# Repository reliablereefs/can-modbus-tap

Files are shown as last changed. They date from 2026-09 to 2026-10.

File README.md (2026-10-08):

# CAN / MODBUS tap

Listen-only probe for a 24 V accessory port that uses a USB-A shell. An ESP32-S3 records classic CAN frames, a collector stores them, and MODBUS RTU payloads inside those frames are decoded into request/response pairs and a register map.

The probe cannot transmit. The isolated CAN transceiver's TXD pin is tied to its logic supply, so the driver stays recessive, and the ESP32 TWAI controller runs in listen-only mode. Use it on equipment you are allowed to monitor.

## Bring-up before any connection

The USB-A plug is not USB. Do not plug it into a computer, and do not use a normal USB cable between the equipment port and anything else. A 24 V pin in that shell will damage a USB host.

1. With the tap unplugged, meter the equipment port.
2. Identify ground and the pin that sits near 24 V.
3. Scope the other two pins. Classic CAN idle holds both near 2.5 V. RS-485 idle is a differential offset without that 2.5 V pair bias.
4. Wire the tap's USB-A plug to match the measured port: pin 1 = 24 V, pin 2 = CANL, pin 3 = CANH, pin 4 = GND. See [docs/hardware.md](docs/hardware.md).
5. Power the tap from its USB-C port. The 24 V pin is measured and is not the tap's supply.
6. Confirm frames in the collector before trusting a bitrate lock.

If the scope does not show CAN bias, stop. This board's controller only decodes classic CAN. An RS-485 MODBUS RTU pair needs a different transceiver.

## Layout

```text
can-modbus-tap/
  docs/hardware.md     board, pinout, isolation, BOM notes
  docs/protocol.md     capture record, upload JSON, MODBUS pairing
  hardware/bom.csv
  firmware/            ESP-IDF project for ESP32-S3
  collector/           SQLite ingest, decode, and browser UI
```

```mermaid
flowchart LR
  port["Equipment port"] --> choke["Choke and TVS"]
  choke --> iso["ISO1042 TXD tied high"]
  iso --> esp["ESP32-S3 listen-only"]
  v24["24 V divider"] --> adc["ADS1115"]
  adc --> i2c["ISO1640"]
  i2c --> esp
  esp --> flash["Flash ring"]
  esp --> col["Collector"]
```

## Firmware

Requires ESP-IDF 5.3. The Wi-Fi SSID and collector URL are compile-time settings, so they stay out of the git tree.

```bash
cd firmware
idf.py set-target esp32s3
idf.py menuconfig   # CAN MODBUS Tap
idf.py build flash monitor
```

Set the SSID, password, and `TAP_COLLECTOR_URL`. Leave bitrate at 0 to scan 25 kbit/s through 1 Mbit/s. Set a fixed rate once the bus is identified. An empty SSID still records to the on-module flash ring.

The activity LED (GPIO2) stays on while frames arrive. GPIO5 is the TWAI transmit test point and is not routed to the transceiver.

## Collector

```bash
cd collector
go run ./cmd/collector -listen 0.0.0.0:8080 -db data/tap.db
```

Open `http://127.0.0.1:8080/`. Pages:

| Path | Contents |
| --- | --- |
| `/` | Raw CAN frames |
| `/modbus` | CRC-valid MODBUS RTU payloads |
| `/transactions` | Request paired with the next response, 500 ms window |
| `/map` | Register addresses sorted by how often they appear |
| `/v1/frames.csv` | Recent raw frames |

`POST /v1/frames` has no authentication. Run the collector on the lab network. Details are in [docs/protocol.md](docs/protocol.md).

```bash
cd collector && go test ./...
```

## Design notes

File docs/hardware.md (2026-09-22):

# Hardware

Passive classic-CAN tap. The field connector is a USB-A plug because the equipment port uses that shell. The plug carries 24 V, ground, and a differential pair. It is not a USB device and it must not be inserted into a USB host.

Power for the ESP32 comes from a separate USB-C receptacle. The 24 V pin is only measured, through an isolated ADC, so a wiring mistake on the field plug does not back-feed the computer used to program the tap.

## Zones

Keep logic ground and bus ground apart with a milled slot under the ISO1042 and the ISO1640. The slot is 2 mm wide, which fits between those packages' pads, and it runs 8 mm past the pads so the creepage path has to go around the slot. The RFM-0505S pins are 2.54 mm apart, so the slot stops before that module; its isolation is the module's own barrier. Logic ground and bus ground meet nowhere.

| Zone | Ground | Supply |
| --- | --- | --- |
| Logic | `GND_LOG` | USB-C 5 V, then 3.3 V for the ESP32 |
| Bus | `GND_BUS` | Isolated 5 V for the CAN transceiver, isolated 3.3 V for the ADC |

## USB-A plug

Standard USB-A pin numbers, used here for a different electrical assignment. Confirm against the equipment port with a meter before connecting. Swap CANH/CANL or the 24 V pin only after that measurement. Do not guess.

| Pin | USB name | This tap |
| --- | --- | --- |
| 1 | VBUS | +24 V sense |
| 2 | D− | CANL |
| 3 | D+ | CANH |
| 4 | GND | Bus ground |
| Shell | Shield | Bus ground |

There is no USB-A receptacle on the tap, so a PC cable cannot be plugged into the 24 V pins through this board.

## CAN front end

Population is ISO1042 in the 16-pin SOIC (DW). Pin numbers below are that package.

| Pin | Name | Connect to |
| --- | --- | --- |
| 1 | VCC1 | `3V3_LOG` |
| 2, 8 | GND1 | `GND_LOG` |
| 3 | TXD | `3V3_LOG` directly |
| 5 | RXD | ESP32 GPIO4 |
| 9, 10, 15 | GND2 | `GND_BUS` |
| 11 and 16 | VCC2 | `5V_BUS`, tied together |
| 12 | CANL | choke, then USB-A pin 2 |
| 13 | CANH | choke, then USB-A pin 3 |

TXD high is recessive. Tying pin 3 to VCC1 means the transceiver cannot drive a dominant bit. The ESP32 still needs a TWAI TX GPIO for the driver; that is GPIO5, a test point, and it does not reach the transceiver. Listen-only mode is a second interlock: the controller does not send data, acknowledgements, or error frames.

100 nF from each VCC pin to its own ground. Common-mode choke in series with CANH and CANL, then NUP2105 from both lines to bus ground. Footprint a 120 Ω resistor across the pair and leave it unstuffed. A tap in the middle of a bus must not add termination. Stuff it only if this node is intentionally an end of the bus, and then only one end.

The ISO1042 tolerates CAN FD on the wire. The ESP32-S3 TWAI controller does not decode CAN FD. A FD-only bus will fail bitrate lock.

## 24 V sense

Bus side only, so the divider never crosses the slot.

`24V` — 91.0 kΩ 1% — node — 12.0 kΩ 1% — `GND_BUS`. 100 nF across the 12.0 kΩ. 1 kΩ from the node to ADS1115 AIN0. BZT52C3V6 from AIN0 to `GND_BUS`.

ADS1115 ADDR pin to `GND_BUS` (I2C address 0x48). AIN1–AIN3 open. Power the ADC and ISO1640 side 2 from `3V3_BUS`, which is an AP2112 from `5V_BUS`.

At 24.00 V the ADC sees 24 × 12 / 103 = 2.796 V. Firmware programs PGA ±4.096 V and reports `bus_mv = code × 103 / 96`.

I2C crosses the slot on ISO1640. 4.7 kΩ pull-ups on each side to that side's 3.3 V. ESP32 GPIO6 is SDA, GPIO7 is SCL.

## Logic power and USB-C

USB-C VBUS feeds AP7361C-33 (1 A) for the ESP32 module. 10 µF on 3.3 V. CC1 and CC2 each have 5.1 kΩ to `GND_LOG`. D+ is GPIO20, D− is GPIO19, each through 22 Ω.

EN has 10 kΩ to 3.3 V, 1 µF to ground, and a button to ground. GPIO0 has 10 kΩ to 3.3 V and a BOOT button to ground. GPIO2 drives the activity LED through 330 Ω.

`5V_USB` also feeds the RECOM RFM-0505S, a 1 W SIP4 module. RECOM rates it 1 kVDC. Pin 1 is -Vin, pin 2 is +Vin, pin 3 is -Vout, and pin 4 is +Vout. The module output is `5V_BUS`.

## ESP32-S3-WROOM-1-N8

| GPIO | Function |
| --- | --- |
| 2 | Activity LED |
| 4 | TWAI RX from ISO1042 RXD |
| 5 | TWAI TX test point only |
| 6 | I2C SDA |
| 7 | I2C SCL |
| 19 | USB D− |
| 20 | USB D+ |
| 0 | BOOT strap, button to ground |

Do not route GPIO26–32; the module uses them for flash.

## How to tell CAN from RS-485

Measure the undriven differential pair against bus ground.

- Both lines near 2.5 V, and they kick apart by about 2 V during a frame: classic CAN. This board matches that.
- One line sits a few hundred millivolts above the other and the common mode is not 2.5 V: likely RS-485 MODBUS RTU. Do not keep this transceiver on that pair. A later board would swap the ISO1042 for an ISO1410 with the driver-enable pin tied off, and the ESP32 would listen on a UART.

## Parts

See [hardware/bom.csv](../hardware/bom.csv). The schematic is [hardware/kicad/can-modbus-tap.kicad_sch](../hardware/kicad/can-modbus-tap.kicad_sch).

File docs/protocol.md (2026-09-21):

# Capture and MODBUS decode

The tap stores every classic CAN frame it locks onto. MODBUS decoding is a best-effort pass over those bytes. The raw frame is kept either way.

## On-device record

Each flash record is 32 bytes, little-endian:

| Offset | Field |
| --- | --- |
| 0 | Magic `0xC0FFEE42` |
| 4 | Sequence, starting at 1 |
| 8 | `ts_us`, monotonic microseconds from boot |
| 16 | CAN id |
| 20 | DLC |
| 21 | Flags: bit 0 extended id, bit 1 remote frame |
| 22 | Index into the bitrate table |
| 24 | 8 data bytes |

The ring lives in the `caps` partition (about 6 MB, 32-byte records). The upload cursor is in NVS. A retried upload of the same sequence is ignored by the collector.

Bitrates the scanner tries, in order: 250k, 500k, 125k, 100k, 50k, 1M, 800k, 25k. A rate is locked when it collects at least two frames in 400 ms without a high receive-error count. Set `TAP_BITRATE` once the rate is known so an idle bus does not have to be scanned.

## Upload

`POST /v1/frames` with `Content-Type: application/json`.

```json
{
  "device_id": "aabbccddeeff",
  "bus_mv": 24120,
  "dropped": 0,
  "bitrate": 250000,
  "boot_unix_us": 1700000000000000,
  "frames": [
    {
      "seq": 12,
      "ts_us": 1530000,
      "id": 385,
      "ext": false,
      "rtr": false,
      "dlc": 8,
      "bitrate": 250000,
      "data": "010300000001"
    }
  ]
}
```

`device_id` is the Wi-Fi MAC, or the menuconfig override. `dropped` is the count of frames that missed the RAM queue since boot. `boot_unix_us` is zero until SNTP locks; after that the collector sets event time to `boot_unix_us + ts_us`, which is comparable across taps. `bus_mv` is -1 when the ADS1115 does not answer.

Empty `frames` is a heartbeat so bus voltage is recorded while the bus is idle. The collector answers `{"stored": N}` where N is newly inserted data frames.

## MODBUS

Bytes are appended per device and CAN id. A gap over 10 ms clears a partial frame. A candidate is accepted when the MODBUS CRC-16 matches and the length matches a known function:

| Function | Request | Response |
| --- | --- | --- |
| 1, 2, 3, 4 | 8 bytes, quantity in range | 5 + byte count |
| 5, 6 | 8 bytes, identical to the response | same 8 bytes, paired when the echo repeats within 500 ms |
| 15, 16 | 9 + byte count | 8 bytes |

Slave address 0 and addresses above 247 are ignored. Exception responses (function code with the high bit set) are 5 bytes. Read Holding (function 3) and Read Input (function 4) responses must have an even byte count.

A CAN id that carries a whole RTU frame in one or more consecutive frames decodes on its own. Pairing does not require the response to use the same CAN id. It matches slave address and function code inside 500 ms, and copies the register address from the request.

If nothing decodes, the payload is not this RTU layout. The frames page is still the source of truth. Some devices put the node address in the CAN id and omit the RTU slave byte; that will not decode until a second pass is written, and the raw bytes are what that pass would use.

## Working a register map

1. Lock bitrate and confirm raw frames.
2. Open `/modbus` and check that function codes and slave addresses look stable rather than random.
3. Open `/transactions` and check latency. Milliseconds, not tens of milliseconds, usually means the response belongs to that request.
4. Open `/map`. Repeated `(slave, function, address, quantity)` rows are the command set. A function 3 row is a read of holding registers. A function 16 row is a write. The address column is the register the master asked for.
5. Export `/v1/frames.csv` when you want to try a different grouping offline. Do not delete the raw frames; the decoder can be wrong about an ambiguous 8-byte function 5 or 6 frame, and the hex is the check.

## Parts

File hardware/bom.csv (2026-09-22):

Qty | Ref | Value | Package | Manufacturer | Part | Notes
1 | U1 | ESP32-S3-WROOM-1-N8 | Module | Espressif | ESP32-S3-WROOM-1-N8 | 8 MB quad flash. Classic CAN only.
1 | U2 | ISO1042 | SOIC-16 | Texas Instruments | ISO1042BDW | Isolated CAN. TXD hard-tied to VCC1. Tie VCC2 pins 11 and 16.
1 | U3 | I2C isolator | SOIC-8 | Texas Instruments | ISO1640BD | Bus-side ADS1115 to ESP32. 3.3 V both sides.
1 | U4 | ADC 16-bit | VSSOP-10 | Texas Instruments | ADS1115IDGSR | ADDR to bus GND. AIN0 is the 24 V divider.
1 | U5 | 5V to 5V 1W isolated | SIP4 | RECOM | RFM-0505S | Pin 1 -Vin, 2 +Vin, 3 -Vout, 4 +Vout. RECOM rates it 1 kVDC.
1 | U6 | 3.3V 1A LDO | SOT-223 | Diodes Inc | AP7361C-33E-13 | USB VBUS to ESP32 3.3 V.
1 | U7 | 3.3V 600mA LDO | SOT-23-5 | Diodes Inc | AP2112K-3.3TRG1 | Bus-side 5 V to 3.3 V for ADS1115 and ISO1640 side 2.
1 | J1 | USB-A plug | USB3-A horizontal | Würth | 692112030100 | Field connector. Not a USB port. See docs/hardware.md pinout.
1 | J2 | USB-C receptacle | USB-C 16P top-mount | GCT | USB4105 | Logic power and native USB programming.
1 | L1 | CAN common-mode choke | ACT45B | TDK | ACT45B-510-2P-TL003 | Between J1 and U2.
1 | D1 | CAN TVS | SOT-23 | onsemi | NUP2105LT1G | CANH CANL and bus GND.
1 | D2 | 3.6V zener | SOD-123 | Nexperia | BZT52C3V6 | Clamp ADS1115 AIN0 to bus GND.
1 | D3 | LED | 0603 |  |  | Activity. On while frames are arriving.
2 | SW1 SW2 | Tactile | 6mm |  |  | SW1 BOOT to GPIO0. SW2 reset to EN.
1 | R1 | 91.0k 1% | 0603 |  |  | 24 V divider top. Bus side only.
1 | R2 | 12.0k 1% | 0603 |  |  | 24 V divider bottom.
1 | R3 | 1k | 0603 |  |  | Series into ADS1115 AIN0.
2 | R4 R5 | 4.7k | 0603 |  |  | I2C pull-ups on the logic side to 3V3_LOG.
2 | R6 R7 | 4.7k | 0603 |  |  | I2C pull-ups on the bus side to 3V3_BUS.
2 | R8 R9 | 5.1k | 0603 |  |  | USB-C CC1 and CC2 to logic GND.
2 | R10 R11 | 10k | 0603 |  |  | EN and GPIO0 pull-ups to 3V3_LOG.
1 | R12 | 330 | 0603 |  |  | LED series.
1 | R13 | 120 1% | 0603 |  |  | DNP. Termination footprint. Leave open.
2 | R14 R15 | 22 | 0603 |  |  | USB D+ and D- series. Optional but recommended.
1 | C1 | 10uF 10V | 0805 |  |  | 3V3_LOG bulk.
4 | C2 C3 C4 C5 | 100nF | 0402 |  |  | U2 VCC1 U2 VCC2 U6 U7.
2 | C6 C7 | 10uF 10V | 0805 |  |  | 5V_BUS and 3V3_BUS bulk.
1 | C8 | 100nF | 0402 |  |  | Across R2.
1 | C9 | 1uF | 0402 |  |  | EN to logic GND.
1 | JP1 | Termination jumper | 0.1in header |  |  | Open. Stuff only if this node is a physical bus end.
1 | TP1 | TWAI TX test point | Pad |  |  | GPIO5. Not connected to the transceiver.

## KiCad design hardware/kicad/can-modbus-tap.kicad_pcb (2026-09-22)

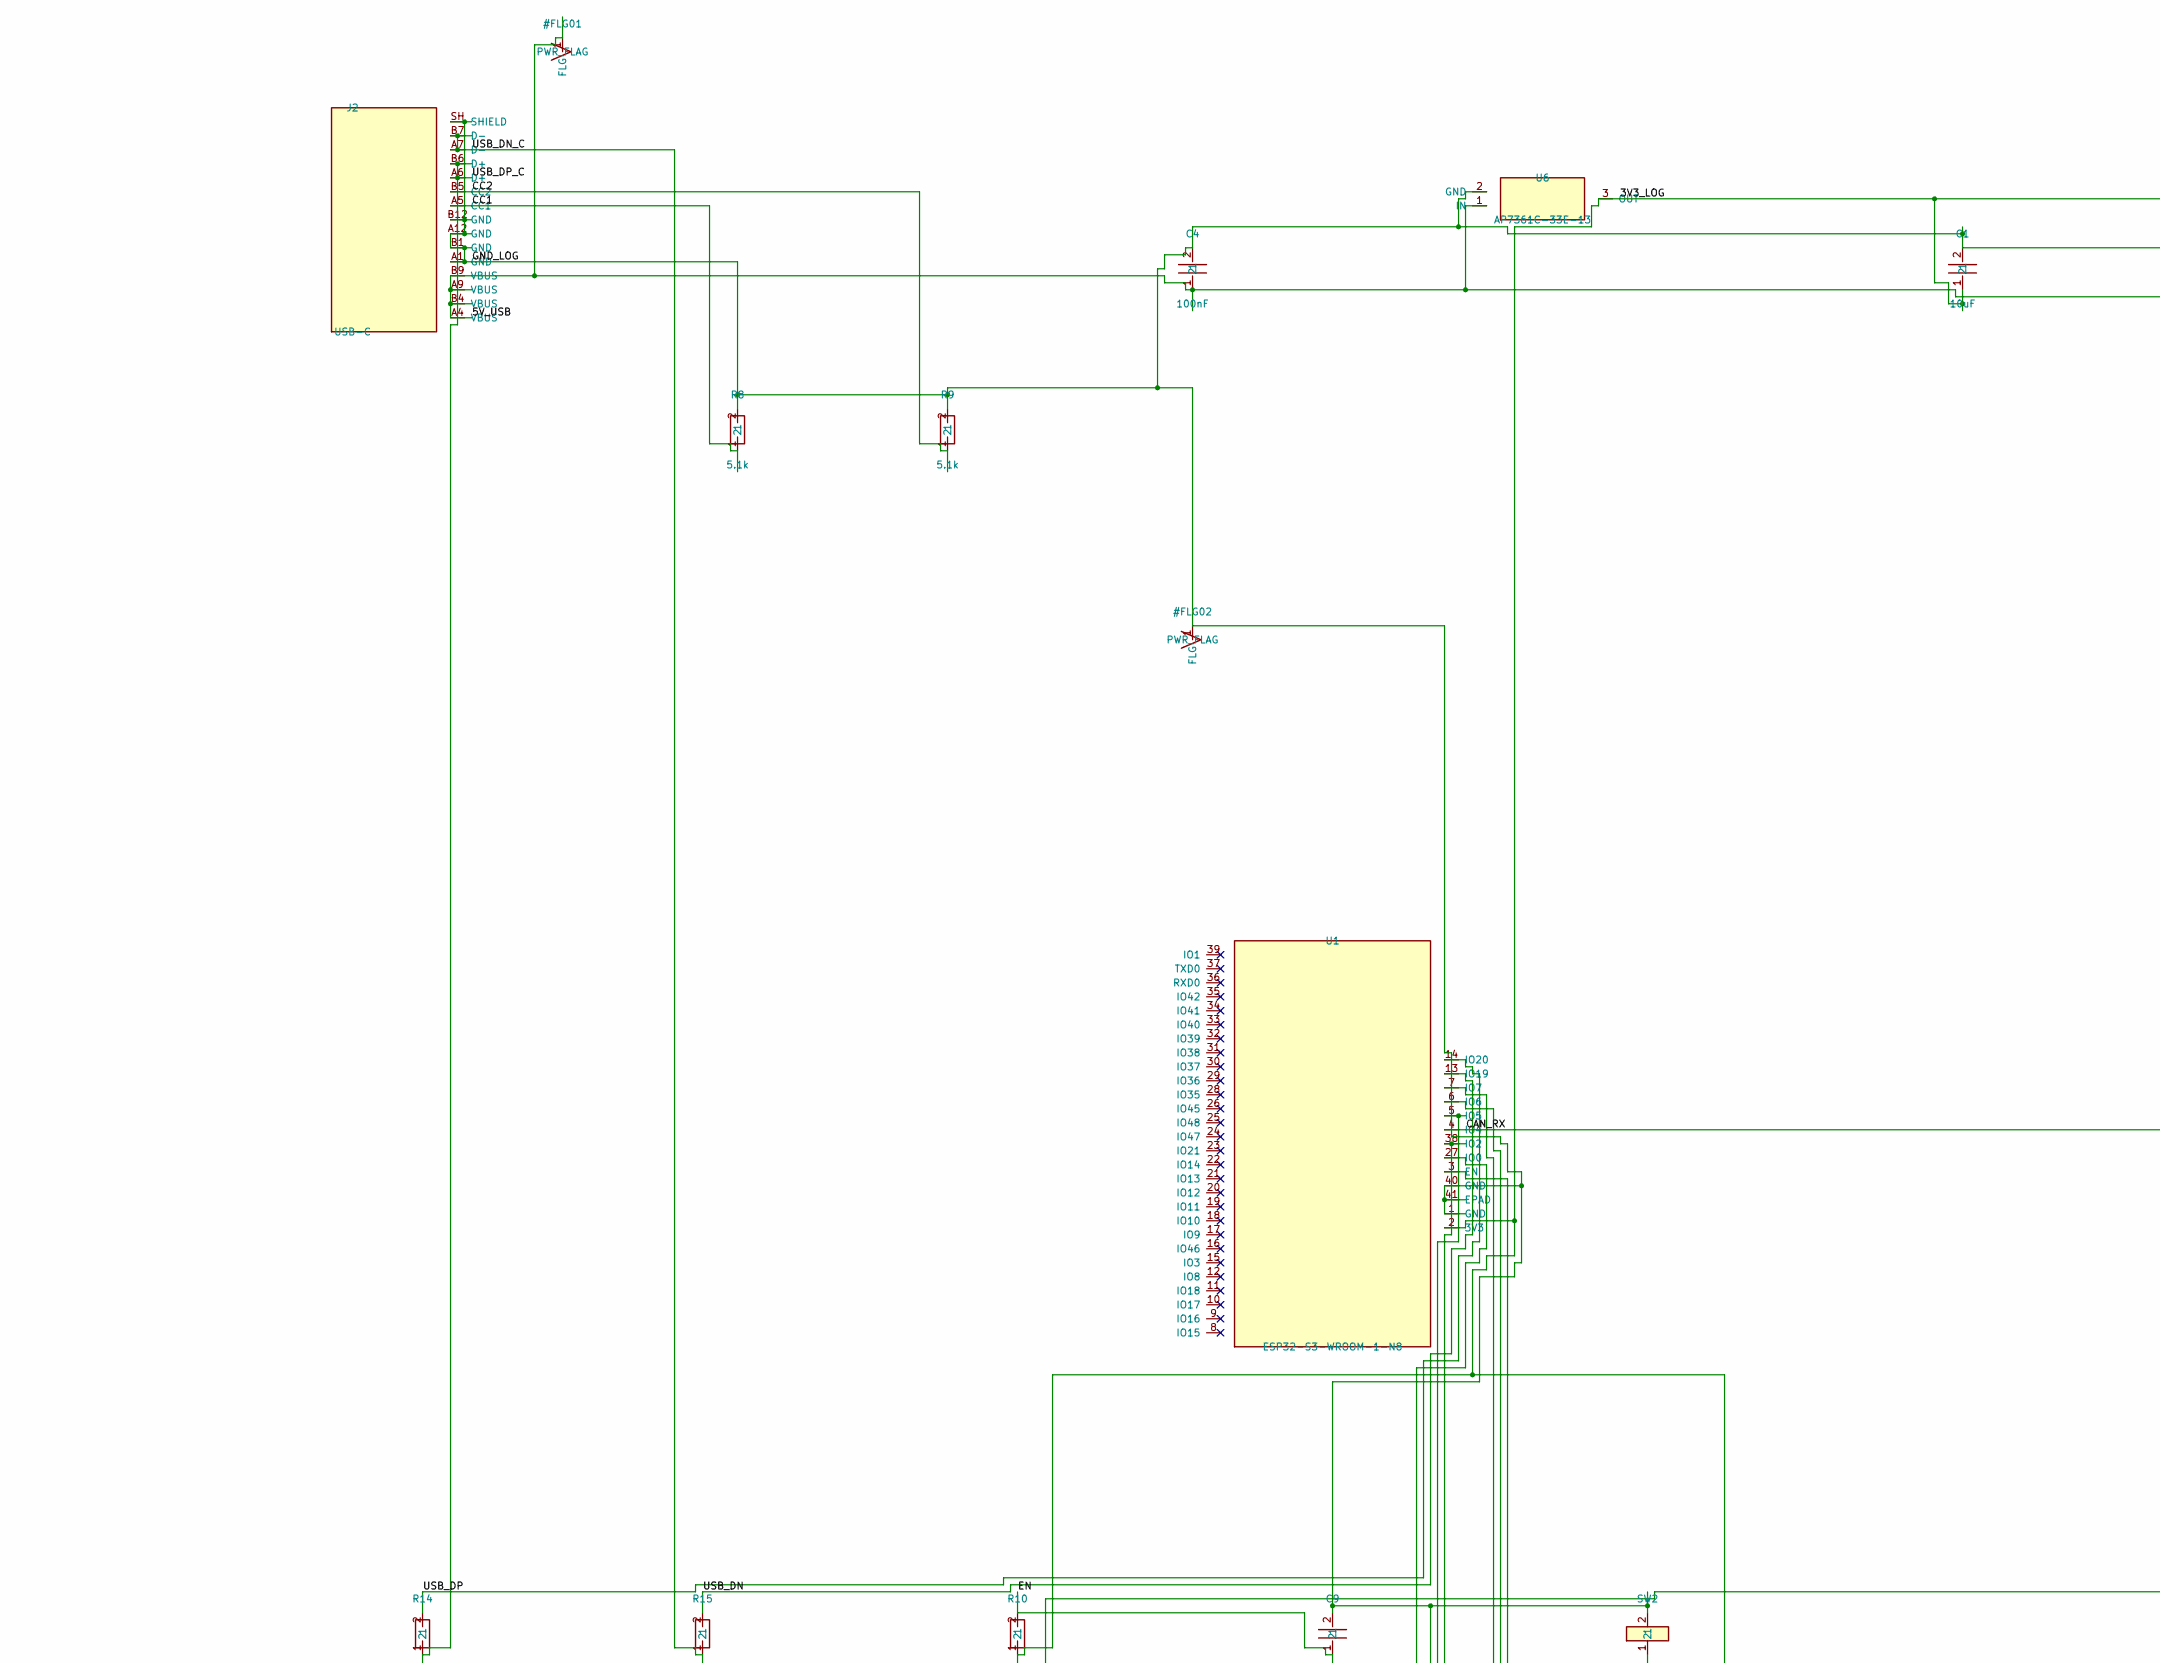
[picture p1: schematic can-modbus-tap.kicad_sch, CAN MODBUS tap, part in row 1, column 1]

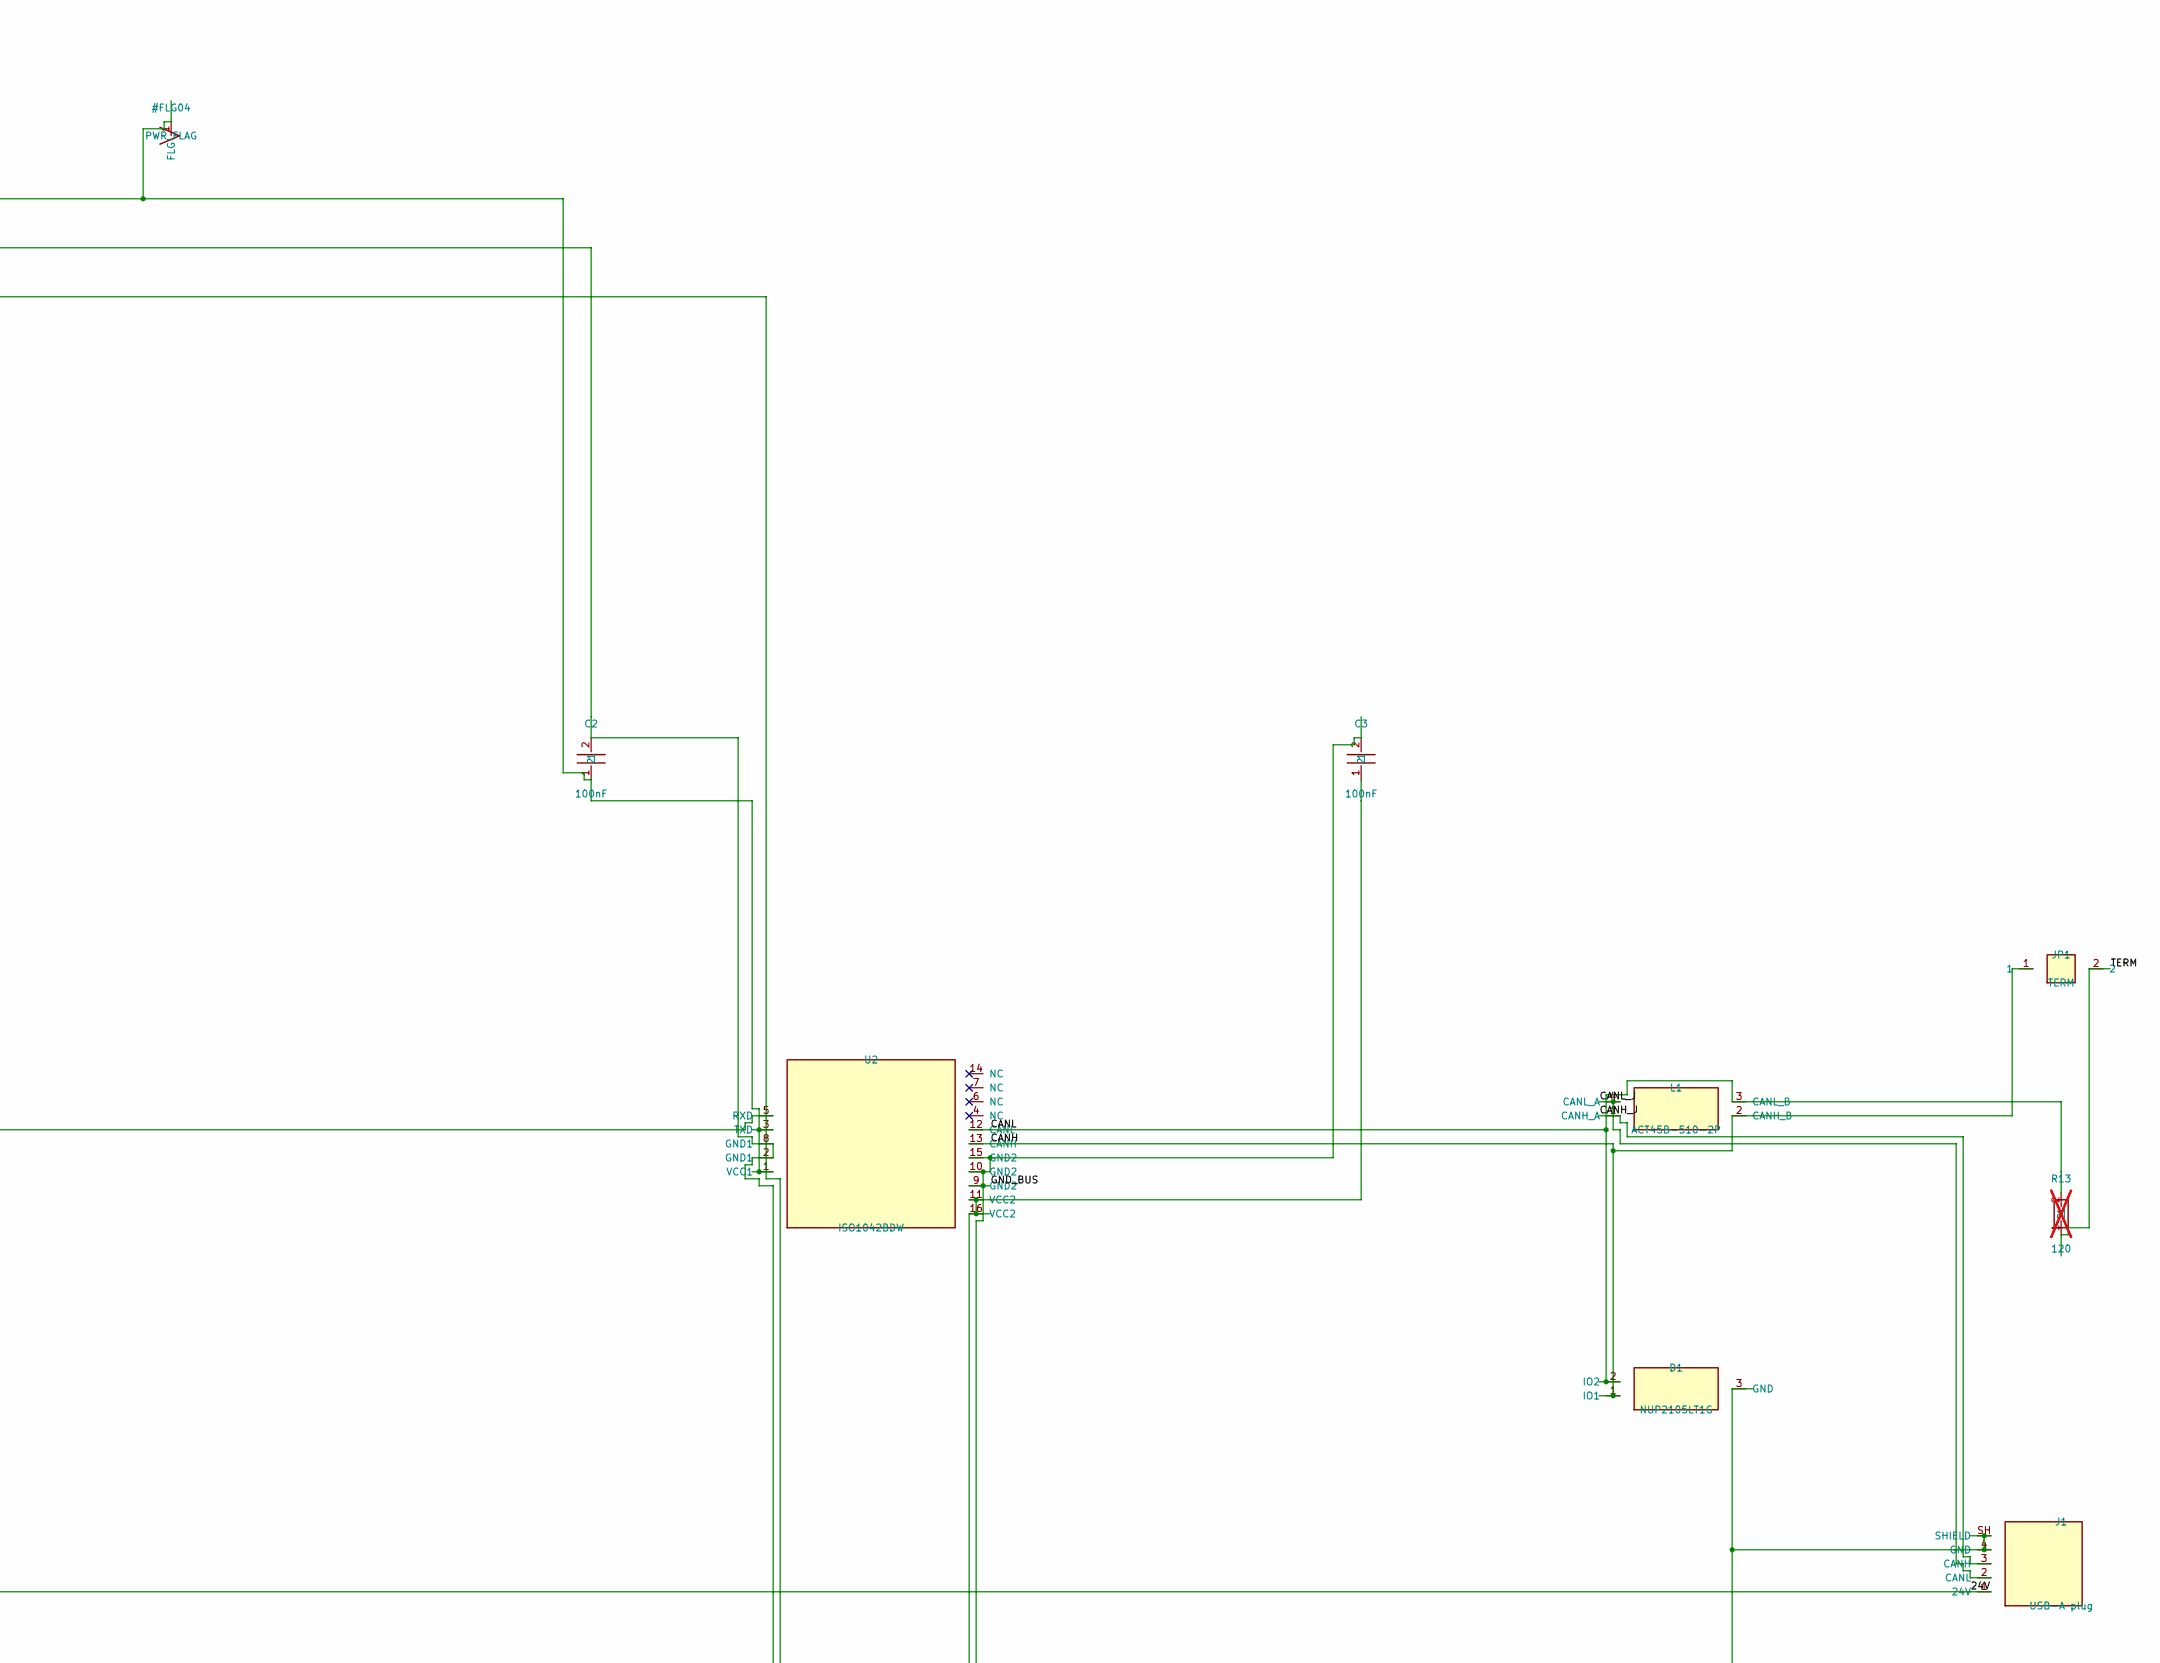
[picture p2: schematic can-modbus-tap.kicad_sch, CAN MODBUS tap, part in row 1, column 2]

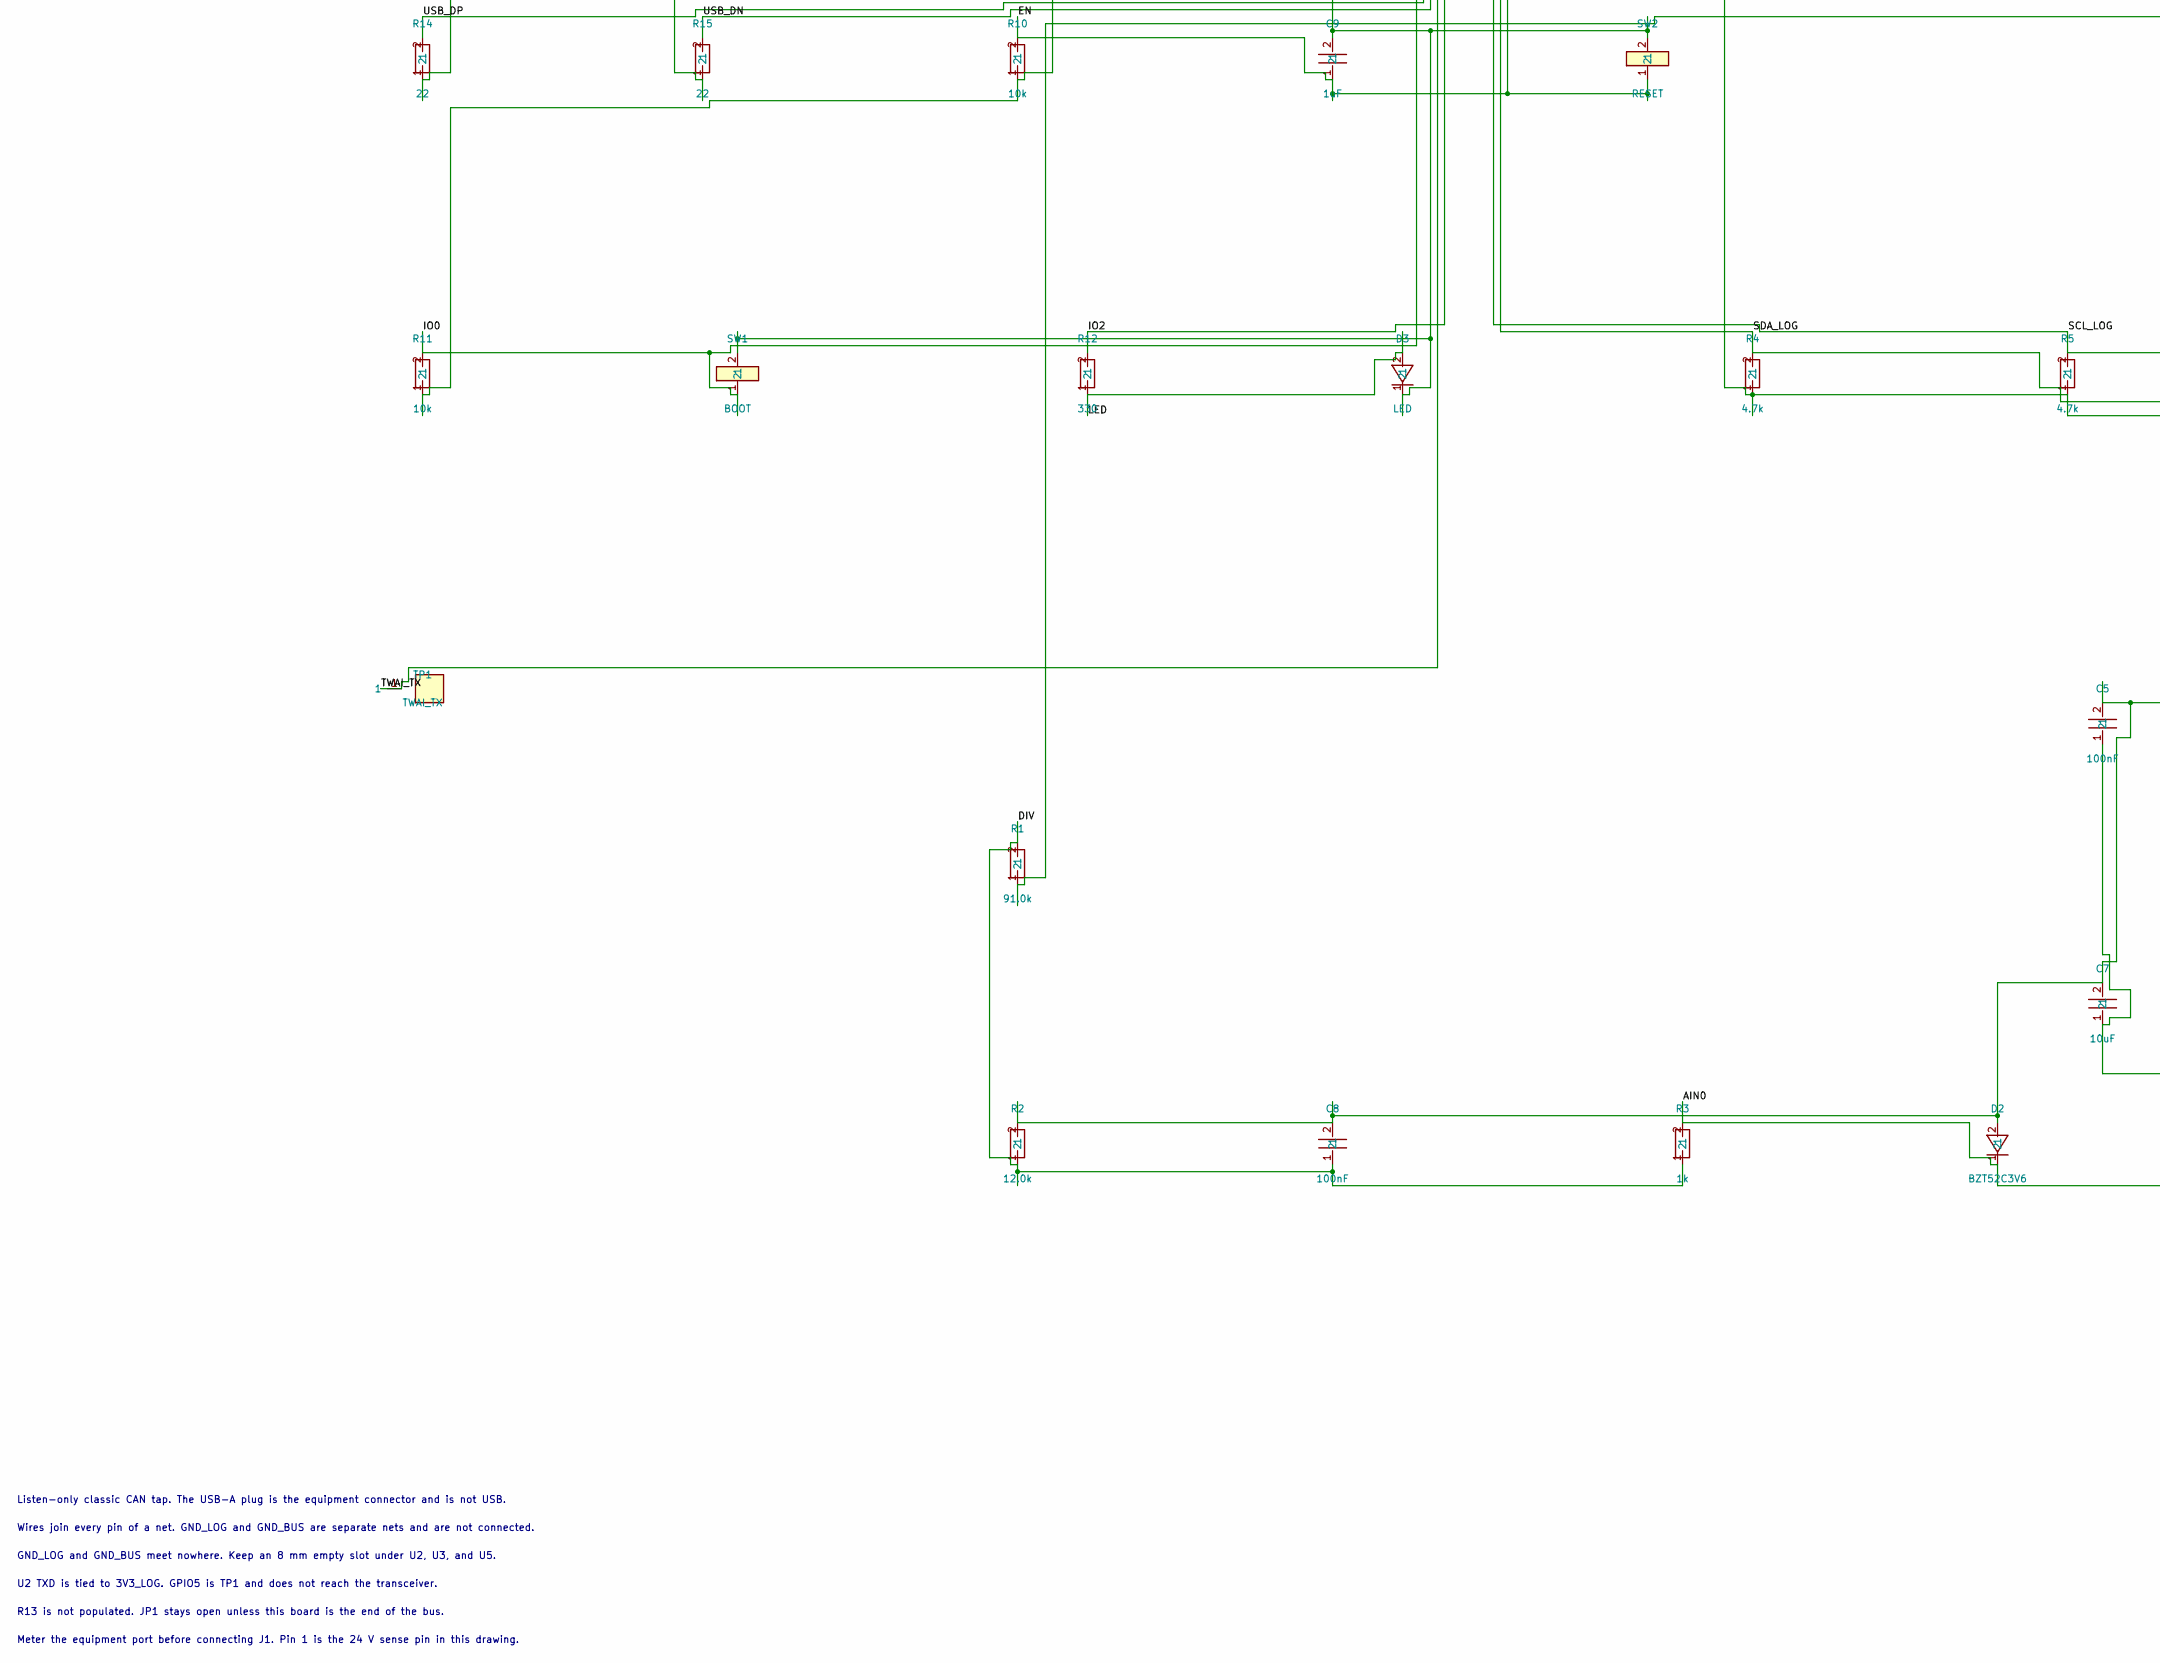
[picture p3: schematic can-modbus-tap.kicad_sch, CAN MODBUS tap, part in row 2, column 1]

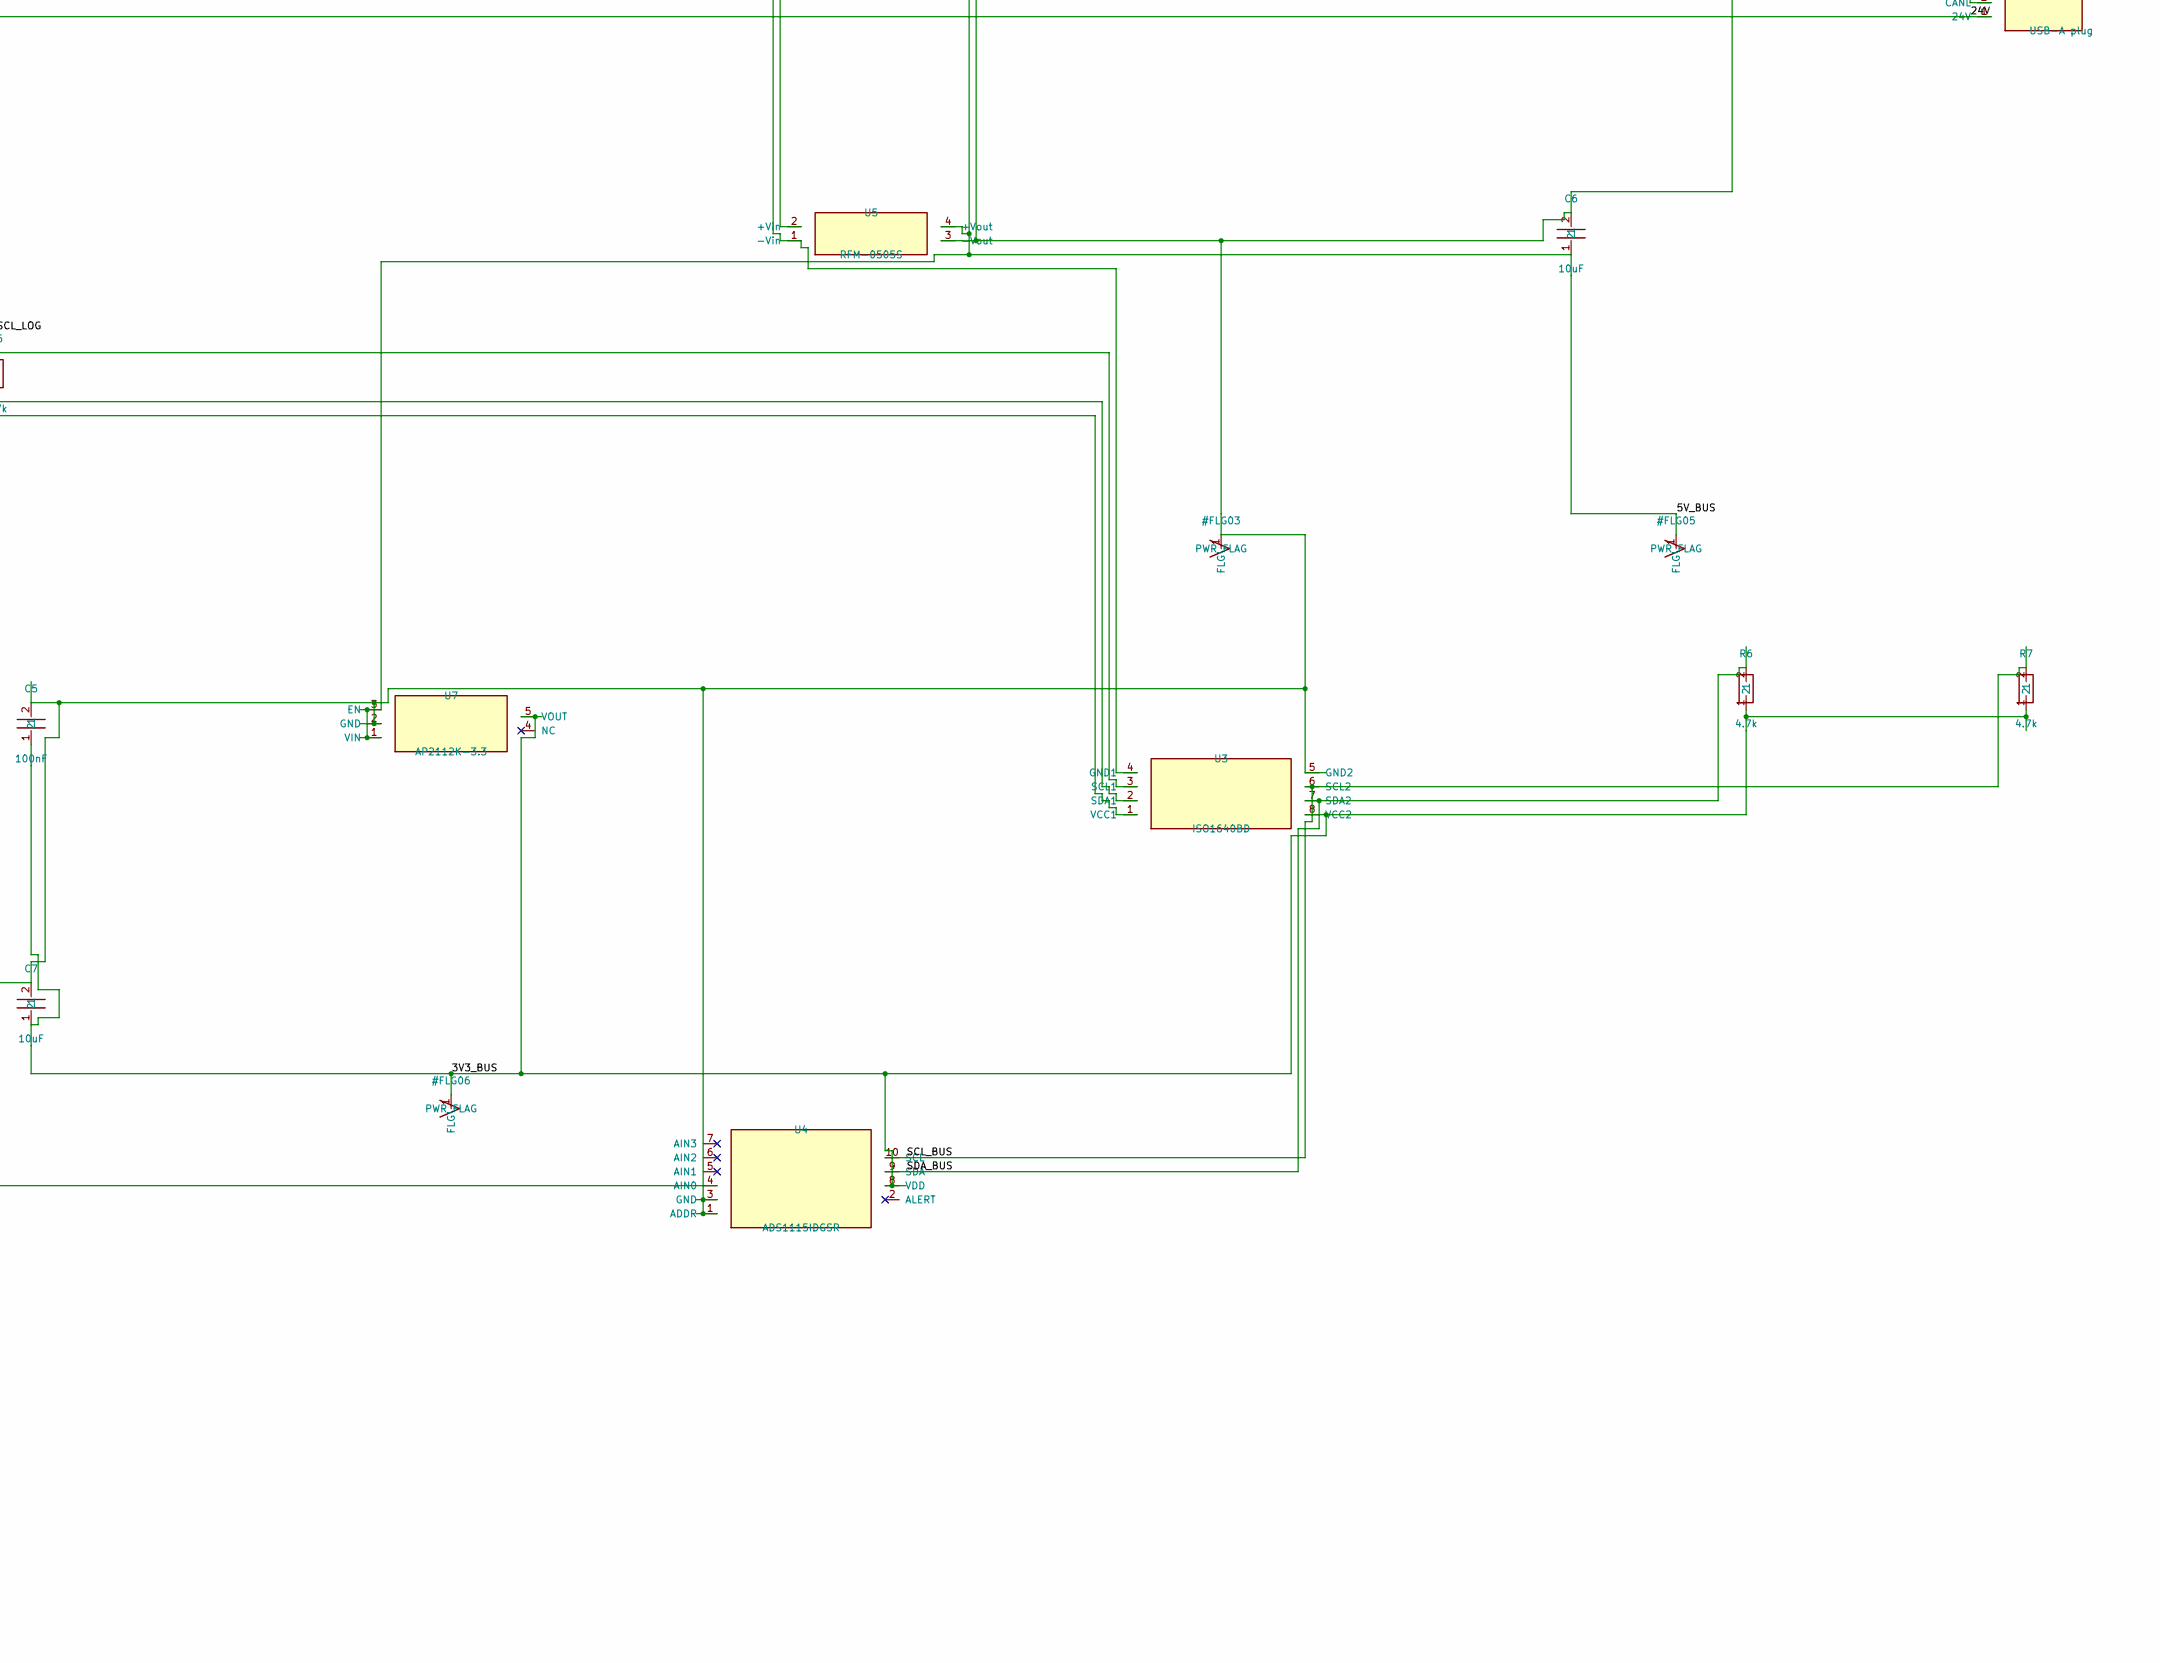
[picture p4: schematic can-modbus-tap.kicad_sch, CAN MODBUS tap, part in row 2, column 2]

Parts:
C1, C6, C7: 10uF; C_0805_2012Metric
C2, C3, C4, C5, C8: 100nF; C_0402_1005Metric
C9: 1uF; C_0402_1005Metric
D1: NUP2105LT1G; SOT-23
D2: BZT52C3V6; D_SOD-123
D3: LED; LED_0603_1608Metric
J1: USB-A plug; USB3_A_Plug_Wuerth_692112030100_Horizontal
J2: USB-C; USB_C_Receptacle_GCT_USB4105-xx-A_16P_TopMnt_Horizontal
JP1: TERM; PinHeader_1x02_P2.54mm_Vertical
L1: ACT45B-510-2P
R1: 91.0k; R_0603_1608Metric
R2: 12.0k; R_0603_1608Metric
R3: 1k; R_0603_1608Metric
R4, R5, R6, R7: 4.7k; R_0603_1608Metric
R8, R9: 5.1k; R_0603_1608Metric
R10, R11: 10k; R_0603_1608Metric
R12: 330; R_0603_1608Metric
R13: 120; R_0603_1608Metric; not fitted
R14, R15: 22; R_0603_1608Metric
SW1: BOOT; SW_PUSH_6mm
SW2: RESET; SW_PUSH_6mm
TP1: TWAI_TX; TestPoint_Pad_D1.5mm
U1: ESP32-S3-WROOM-1-N8; ESP32-S3-WROOM-1
U2: ISO1042BDW; SOIC-16W_7.5x10.3mm_P1.27mm
U3: ISO1640BD; SOIC-8_3.9x4.9mm_P1.27mm
U4: ADS1115IDGSR; MSOP-10_3x3mm_P0.5mm
U5: RFM-0505S; RECOM_RFM-0505S
U6: AP7361C-33E-13; SOT-223-3_TabPin2
U7: AP2112K-3.3; SOT-23-5

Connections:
3V3_BUS: C5.1, C7.1, R6.1, R7.1, U3.8 (VCC2), U4.8 (VDD), U7.5 (VOUT)
3V3_LOG: C1.1, C2.1, R4.1, R5.1, R10.1, R11.1, U1.2 (3V3), U2.1 (VCC1), U2.3 (TXD), U3.1 (VCC1), U6.3 (OUT)
5V_BUS: C3.1, C6.1, U2.11 (VCC2), U2.16 (VCC2), U5.4 (+Vout), U7.1 (VIN), U7.3 (EN)
5V_USB: C4.1, J2.A4 (VBUS), J2.A9 (VBUS), J2.B4 (VBUS), J2.B9 (VBUS), U5.2 (+Vin), U6.1 (IN)
24V: J1.1 (24V), R1.1
AIN0: D2.1, R3.2, U4.4 (AIN0)
CANH: D1.1 (IO1), JP1.1, L1.2 (CANH_B), U2.13 (CANH)
CANH_J: J1.3 (CANH), L1.1 (CANH_A)
CANL: D1.2 (IO2), L1.3 (CANL_B), R13.2, U2.12 (CANL)
CANL_J: J1.2 (CANL), L1.4 (CANL_A)
CAN_RX: U1.4 (IO4), U2.5 (RXD)
CC1: J2.A5 (CC1), R8.1
CC2: J2.B5 (CC2), R9.1
DIV: C8.1, R1.2, R2.1, R3.1
EN: C9.1, R10.2, SW2.1, U1.3 (EN)
GND_BUS: C3.2, C5.2, C6.2, C7.2, C8.2, D1.3 (GND), D2.2, J1.4 (GND), J1.SH (SHIELD), R2.2, U2.9 (GND2), U2.10 (GND2), U2.15 (GND2), U3.5 (GND2), U4.1 (ADDR), U4.3 (GND), U5.3 (-Vout), U7.2 (GND)
GND_LOG: C1.2, C2.2, C4.2, C9.2, D3.1, J2.A1 (GND), J2.A12 (GND), J2.B1 (GND), J2.B12 (GND), J2.SH (SHIELD), R8.2, R9.2, SW1.2, SW2.2, U1.1 (GND), U1.40 (GND), U1.41 (EPAD), U2.2 (GND1), U2.8 (GND1), U3.4 (GND1), U5.1 (-Vin), U6.2 (GND)
IO0: R11.2, SW1.1, U1.27 (IO0)
IO2: R12.2, U1.38 (IO2)
LED: D3.2, R12.1
SCL_BUS: R7.2, U3.6 (SCL2), U4.10 (SCL)
SCL_LOG: R5.2, U1.7 (IO7), U3.3 (SCL1)
SDA_BUS: R6.2, U3.7 (SDA2), U4.9 (SDA)
SDA_LOG: R4.2, U1.6 (IO6), U3.2 (SDA1)
TERM: JP1.2, R13.1
TWAI_TX: TP1.1, U1.5 (IO5)
USB_DN: R15.2, U1.13 (IO19)
USB_DN_C: J2.A7 (D-), J2.B7 (D-), R15.1
USB_DP: R14.2, U1.14 (IO20)
USB_DP_C: J2.A6 (D+), J2.B6 (D+), R14.1

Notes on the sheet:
Listen-only classic CAN tap. The USB-A plug is the equipment connector and is not USB.
Wires join every pin of a net. GND_LOG and GND_BUS are separate nets and are not connected.
GND_LOG and GND_BUS meet nowhere. Keep an 8 mm empty slot under U2, U3, and U5.
U2 TXD is tied to 3V3_LOG. GPIO5 is TP1 and does not reach the transceiver.
R13 is not populated. JP1 stays open unless this board is the end of the bus.
Meter the equipment port before connecting J1. Pin 1 is the 24 V sense pin in this drawing.

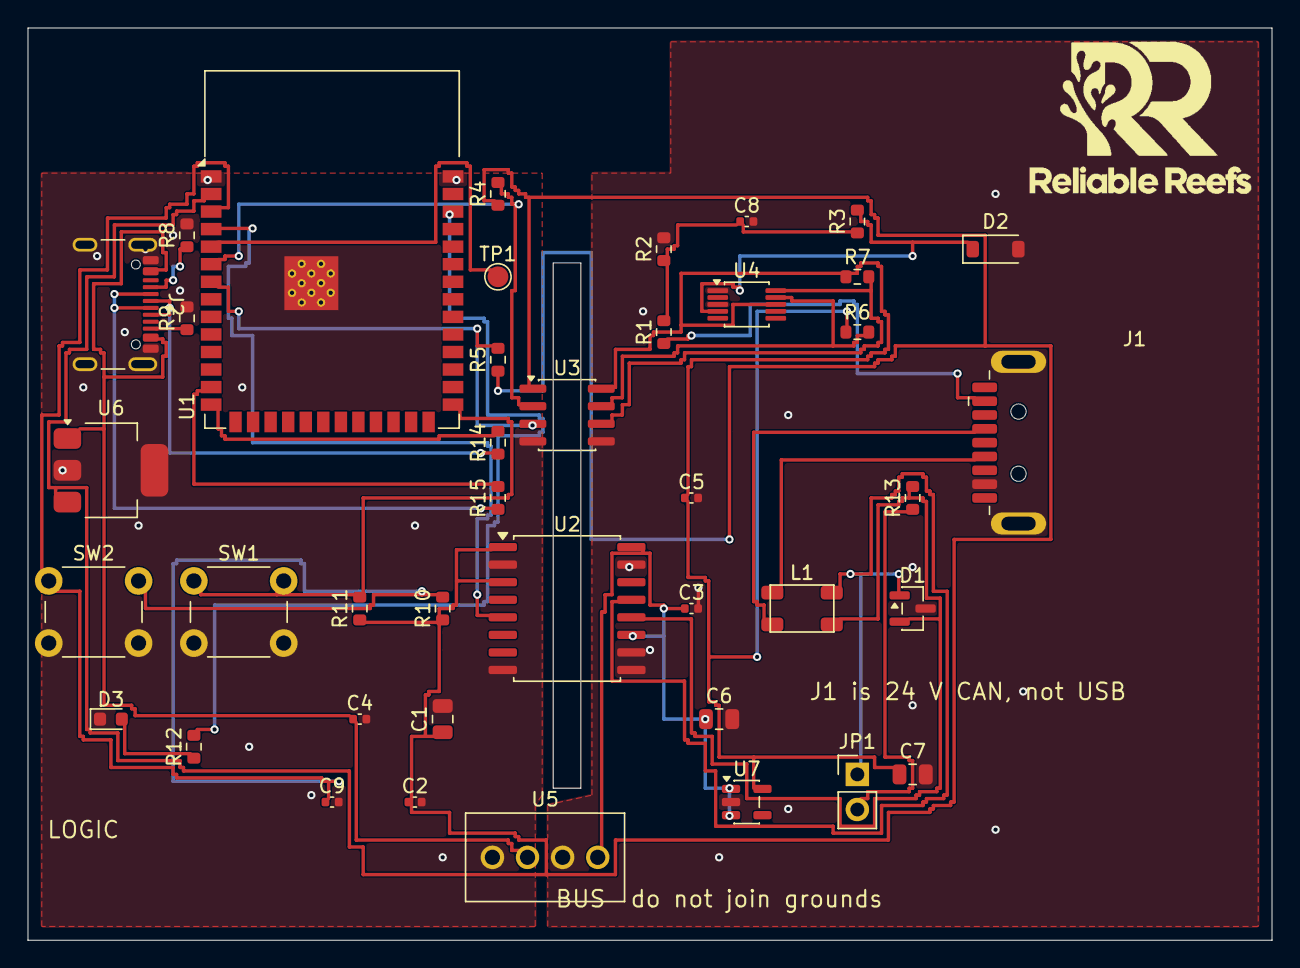
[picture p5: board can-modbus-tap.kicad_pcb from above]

Board: 2 copper layers, 90.0 x 66.0 mm, 41 parts (0 on the bottom side), 30 nets.

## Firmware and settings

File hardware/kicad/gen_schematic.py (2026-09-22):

#!/usr/bin/env python3
"""Generate the CAN / MODBUS tap schematic.

KiCad is not required to regenerate the file. Open hardware/kicad/can-modbus-tap.kicad_sch
in KiCad 8 or 9. Symbols are embedded, so no symbol library is required.
"""

from __future__ import annotations

import heapq
import uuid
from collections import defaultdict
from dataclasses import dataclass, field
from pathlib import Path

GRID = 1.27
OUT = Path(__file__).with_name("can-modbus-tap.kicad_sch")
PROJECT = "can-modbus-tap"


def mm(units: float) -> str:
    value = round(units * GRID, 4)
    text = f"{value:.4f}".rstrip("0").rstrip(".")
    return text if text else "0"


def q(text: str) -> str:
    return '"' + text.replace("\\", "\\\\").replace('"', '\\"') + '"'


def uid() -> str:
    return str(uuid.uuid4())


@dataclass
class Pin:
    num: str
    name: str
    side: str  # L R U D
    etype: str
    x: float = 0
    y: float = 0
    angle: int = 0


@dataclass
class Sym:
    lib_id: str
    pins: list[Pin]
    body_w: float = 10
    graphics: str = "box"

    def layout(self) -> None:
        groups = {side: [pin for pin in self.pins if pin.side == side] for side in "LRUD"}
        for side in "LR":
            pins = groups[side]
            span = (len(pins) - 1) * 2 if pins else 0
            y = -span / 2
            for pin in pins:
                pin.y = y
                pin.x = -self.body_w if side == "L" else self.body_w
                pin.angle = 180 if side == "L" else 0
                y += 2
        for side in "UD":
            pins = groups[side]
            span = (len(pins) - 1) * 2 if pins else 0
            x = -span / 2
            for pin in pins:
                pin.x = x
                pin.y = -self.body_w if side == "U" else self.body_w
                pin.angle = 90 if side == "U" else 270
                x += 2

    def height(self) -> float:
        ys = [pin.y for pin in self.pins] or [0]
        return max(ys) - min(ys) + 4

    def width(self) -> float:
        xs = [pin.x for pin in self.pins] or [0]
        return max(xs) - min(xs) + 4


@dataclass
class Inst:
    sym: str
    ref: str
    value: str
    footprint: str
    nets: dict[str, str | None]
    x: float = 0
    y: float = 0
    dnp: bool = False
    bom: bool = True
    board: bool = True
    description: str = ""


def box_symbol(lib_id: str, pins: list[tuple], body_w: float = 12) -> Sym:
    parsed = [Pin(num, name, side, etype) for num, name, side, etype in pins]
    sym = Sym(lib_id, parsed, body_w=body_w)
    sym.layout()
    return sym


def passive(lib_id: str, kind: str) -> Sym:
    pins = [Pin("1", "1", "U", "passive"), Pin("2", "2", "D", "passive")]
    return Sym(lib_id, pins, body_w=3, graphics=kind)


def flag_symbol() -> Sym:
    pins = [Pin("1", "FLG", "D", "power_out")]
    return Sym("tap:PWR_FLAG", pins, body_w=2, graphics="flag")


def symbol_sexpr(sym: Sym) -> str:
    sym.layout()
    lines = [
        f"    (symbol {q(sym.lib_id)}",
        "      (pin_names (offset 1.016))",
        "      (exclude_from_sim no)",
        "      (in_bom yes)",
        "      (on_board yes)",
    ]
    for name, value, hide in (
        ("Reference", sym.lib_id.split(":")[-1], False),
        ("Value", sym.lib_id.split(":")[-1], False),
        ("Footprint", "", True),
        ("Datasheet", "", True),
        ("Description", "", True),
    ):
        hide_token = "\n          hide" if hide else ""
        lines.append(
            f"      (property {q(name)} {q(value)} (at 0 0 0)\n"
            f"        (effects (font (size 1.27 1.27)){hide_token})\n"
            "      )"
        )
    lefts = [pin.x for pin in sym.pins if pin.side == "L"]
    rights = [pin.x for pin in sym.pins if pin.side == "R"]
    ups = [pin.y for pin in sym.pins if pin.side == "U"]
    downs = [pin.y for pin in sym.pins if pin.side == "D"]
    left = (min(lefts) + 2) if lefts else -3
    right = (max(rights) - 2) if rights else 3
    top = (min(ups) + 2) if ups else min(pin.y for pin in sym.pins) - 2
    bottom = (max(downs) - 2) if downs else max(pin.y for pin in sym.pins) + 2
    if sym.graphics == "box":
        body = (
            f"        (rectangle (start {mm(left)} {mm(top)}) (end {mm(right)} {mm(bottom)})\n"
            "          (stroke (width 0.254) (type default))\n"
            "          (fill (type background))\n"
            "        )"
        )
    elif sym.graphics == "r":
        body = (
            f"        (rectangle (start {mm(-1)} {mm(-2)}) (end {mm(1)} {mm(2)})\n"
            "          (stroke (width 0.254) (type default))\n"
            "          (fill (type none))\n"
            "        )"
        )
    elif sym.graphics == "c":
        body = (
            f"        (polyline (pts (xy {mm(-2)} {mm(-0.6)}) (xy {mm(2)} {mm(-0.6)}))\n"
            "          (stroke (width 0.254) (type default)) (fill (type none)))\n"
            f"        (polyline (pts (xy {mm(-2)} {mm(0.6)}) (xy {mm(2)} {mm(0.6)}))\n"
            "          (stroke (width 0.254) (type default)) (fill (type none)))"
        )
    elif sym.graphics == "d":
        body = (
            f"        (polyline (pts (xy {mm(-1.5)} {mm(1.2)}) (xy {mm(1.5)} {mm(1.2)}) (xy {mm(0)} {mm(-1.2)}) (xy {mm(-1.5)} {mm(1.2)}))\n"
            "          (stroke (width 0.254) (type default)) (fill (type none)))\n"
            f"        (polyline (pts (xy {mm(-1.5)} {mm(-1.6)}) (xy {mm(1.5)} {mm(-1.6)}))\n"
            "          (stroke (width 0.254) (type default)) (fill (type none)))"
        )
    else:
        body = (
            f"        (polyline (pts (xy {mm(-1.6)} {mm(-1.2)}) (xy {mm(1.2)} {mm(0)}) (xy {mm(-1.6)} {mm(1.2)}))\n"
            "          (stroke (width 0.254) (type default)) (fill (type none)))"
        )
    # KiCad stores the name after the library prefix, so units are "R_0_1", not "tap:R_0_1".
    item = sym.lib_id.split(":", 1)[-1]
    lines.append(f"      (symbol {q(item + '_0_1')}")
    lines.append(body)
    lines.append("      )")
    lines.append(f"      (symbol {q(item + '_1_1')}")
    for pin in sym.pins:
        lines.append(
            f"        (pin {pin.etype} line (at {mm(pin.x)} {mm(pin.y)} {pin.angle}) (length 2.54)\n"
            f"          (name {q(pin.name)} (effects (font (size 1.27 1.27))))\n"
            f"          (number {q(pin.num)} (effects (font (size 1.27 1.27))))\n"
            "        )"
        )
    lines.append("      )")
    lines.append("    )")
    return "\n".join(lines)


def direction(angle: int) -> tuple[int, int]:
    return {0: (1, 0), 90: (0, -1), 180: (-1, 0), 270: (0, 1)}[angle]


def pin_on_sheet(inst: Inst, pin: Pin) -> tuple[int, int, int, int]:
    """Map a symbol pin onto the sheet.

    KiCad's rotation-0 placement mirrors the symbol vertically, so a pin stored
    at local +Y lands at instance Y minus that offset.
    """
    dx, dy = direction(pin.angle)
    return grid(inst.x + pin.x), grid(inst.y - pin.y), dx, -dy


def instance_sexpr(inst: Inst, symbols: dict[str, Sym]) -> str:
    sym = symbols[inst.sym]
    chunks = [
        "  (symbol",
        f"    (lib_id {q(inst.sym)})",
        f"    (at {mm(inst.x)} {mm(inst.y)} 0)",
        "    (unit 1)",
        "    (exclude_from_sim no)",
        f"    (in_bom {'yes' if inst.bom else 'no'})",
        f"    (on_board {'yes' if inst.board else 'no'})",
        f"    (dnp {'yes' if inst.dnp else 'no'})",
        f"    (uuid {q(uid())})",
    ]
    ref_y = inst.y - max(pin.y for pin in sym.pins) - 2
    val_y = inst.y - min(pin.y for pin in sym.pins) + 2
    props = [
        ("Reference", inst.ref, ref_y, False),
        ("Value", inst.value, val_y, False),
        ("Footprint", inst.footprint, inst.y, True),
        ("Datasheet", "", inst.y, True),
        ("Description", inst.description, inst.y, True),
    ]
    for name, value, y, hide in props:
        hide_token = "\n        hide" if hide else ""
        chunks.append(
            f"    (property {q(name)} {q(value)} (at {mm(inst.x)} {mm(y)} 0)\n"
            f"      (effects (font (size 1.27 1.27)){hide_token})\n"
            "    )"
        )
    for pin in sym.pins:
        chunks.append(f'    (pin {q(pin.num)} (uuid {q(uid())}))')
    chunks.append("    (instances")
    chunks.append(f'      (project {q(PROJECT)}')
    chunks.append('        (path "/"')
    chunks.append(f"          (reference {q(inst.ref)})")
    chunks.append("          (unit 1)")
    chunks.append("        )")
    chunks.append("      )")
    chunks.append("    )")
    chunks.append("  )")
    return "\n".join(chunks)


def build() -> tuple[dict[str, Sym], list[Inst], list[str]]:
    symbols: dict[str, Sym] = {}

    def add(sym: Sym) -> None:
        sym.layout()
        symbols[sym.lib_id] = sym

    add(passive("tap:R", "r"))
    add(passive("tap:C", "c"))
    add(passive("tap:D", "d"))
    add(flag_symbol())
    add(box_symbol("tap:SW", [("1", "1", "U", "passive"), ("2", "2", "D", "passive")], 3))
    symbols["tap:SW"].graphics = "box"
    add(box_symbol("tap:JP", [("1", "1", "L", "passive"), ("2", "2", "R", "passive")], 4))
    add(box_symbol("tap:TP", [("1", "1", "L", "passive")], 3))

    esp_pins = [
        ("2", "3V3", "R", "power_in"),
        ("1", "GND", "R", "power_in"),
        ("41", "EPAD", "R", "power_in"),
        ("40", "GND", "R", "power_in"),
        ("3", "EN", "R", "input"),
        ("27", "IO0", "R", "bidirectional"),
        ("38", "IO2", "R", "output"),
        ("4", "IO4", "R", "input"),
        ("5", "IO5", "R", "output"),
        ("6", "IO6", "R", "bidirectional"),
        ("7", "IO7", "R", "bidirectional"),
        ("13", "IO19", "R", "bidirectional"),
        ("14", "IO20", "R", "bidirectional"),
    ]
    unused = [
        ("8", "IO15"), ("9", "IO16"), ("10", "IO17"), ("11", "IO18"), ("12", "IO8"),
        ("15", "IO3"), ("16", "IO46"), ("17", "IO9"), ("18", "IO10"), ("19", "IO11"),
        ("20", "IO12"), ("21", "IO13"), ("22", "IO14"), ("23", "IO21"), ("24", "IO47"),
        ("25", "IO48"), ("26", "IO45"), ("28", "IO35"), ("29", "IO36"), ("30", "IO37"),
        ("31", "IO38"), ("32", "IO39"), ("33", "IO40"), ("34", "IO41"), ("35", "IO42"),
        ("36", "RXD0"), ("37", "TXD0"), ("39", "IO1"),
    ]
    esp_pins.extend((num, name, "L", "bidirectional") for num, name in unused)
    add(box_symbol("tap:ESP32-S3-WROOM-1", esp_pins, 16))

    add(box_symbol("tap:ISO1042", [
        ("1", "VCC1", "L", "power_in"),
        ("2", "GND1", "L", "power_in"),
        ("8", "GND1", "L", "power_in"),
        ("3", "TXD", "L", "input"),
        ("5", "RXD", "L", "output"),
        ("16", "VCC2", "R", "power_in"),
        ("11", "VCC2", "R", "power_in"),
        ("9", "GND2", "R", "power_in"),
        ("10", "GND2", "R", "power_in"),
        ("15", "GND2", "R", "power_in"),
        ("13", "CANH", "R", "bidirectional"),
        ("12", "CANL", "R", "bidirectional"),
        ("4", "NC", "R", "passive"),
        ("6", "NC", "R", "passive"),
        ("7", "NC", "R", "passive"),
        ("14", "NC", "R", "passive"),
    ], 14))

    add(box_symbol("tap:ISO1640", [
        ("1", "VCC1", "L", "power_in"),
        ("2", "SDA1", "L", "bidirectional"),
        ("3", "SCL1", "L", "bidirectional"),
        ("4", "GND1", "L", "power_in"),
        ("8", "VCC2", "R", "power_in"),
        ("7", "SDA2", "R", "bidirectional"),
        ("6", "SCL2", "R", "bidirectional"),
        ("5", "GND2", "R", "power_in"),
    ], 12))

    add(box_symbol("tap:ADS1115", [
        ("1", "ADDR", "L", "input"),
        ("3", "GND", "L", "power_in"),
        ("4", "AIN0", "L", "input"),
        ("5", "AIN1", "L", "input"),
        ("6", "AIN2", "L", "input"),
        ("7", "AIN3", "L", "input"),
        ("2", "ALERT", "R", "open_collector"),
        ("8", "VDD", "R", "power_in"),
        ("9", "SDA", "R", "bidirectional"),
        ("10", "SCL", "R", "input"),
    ], 12))

    add(box_symbol("tap:RFM", [
        ("1", "-Vin", "L", "power_in"),
        ("2", "+Vin", "L", "power_in"),
        ("3", "-Vout", "R", "power_in"),
        ("4", "+Vout", "R", "power_out"),
    ], 10))

    add(box_symbol("tap:AP7361", [
        ("1", "IN", "L", "power_in"),
        ("2", "GND", "L", "power_in"),
        ("3", "OUT", "R", "power_out"),
    ], 8))

    add(box_symbol("tap:AP2112", [
        ("1", "VIN", "L", "power_in"),
        ("2", "GND", "L", "power_in"),
        ("3", "EN", "L", "input"),
        ("4", "NC", "R", "passive"),
        ("5", "VOUT", "R", "power_out"),
    ], 10))

    add(box_symbol("tap:USB-C", [
        ("A4", "VBUS", "R", "passive"),
        ("B4", "VBUS", "R", "passive"),
        ("A9", "VBUS", "R", "passive"),
        ("B9", "VBUS", "R", "passive"),
        ("A1", "GND", "R", "passive"),
        ("B1", "GND", "R", "passive"),
        ("A12", "GND", "R", "passive"),
        ("B12", "GND", "R", "passive"),
        ("A5", "CC1", "R", "passive"),
        ("B5", "CC2", "R", "passive"),
        ("A6", "D+", "R", "passive"),
        ("B6", "D+", "R", "passive"),
        ("A7", "D-", "R", "passive"),
        ("B7", "D-", "R", "passive"),
        ("SH", "SHIELD", "R", "passive"),
    ], 14))

    add(box_symbol("tap:USB-A", [
        ("1", "24V", "L", "passive"),
        ("2", "CANL", "L", "passive"),
        ("3", "CANH", "L", "passive"),
        ("4", "GND", "L", "passive"),
        ("SH", "SHIELD", "L", "passive"),
    ], 10))

    add(box_symbol("tap:CMC", [
        ("1", "CANH_A", "L", "passive"),
        ("4", "CANL_A", "L", "passive"),
        ("2", "CANH_B", "R", "passive"),
        ("3", "CANL_B", "R", "passive"),
    ], 8))

    add(box_symbol("tap:NUP2105", [
        ("1", "IO1", "L", "passive"),
        ("2", "IO2", "L", "passive"),
        ("3", "GND", "R", "passive"),
    ], 8))

    gnd_l, gnd_b = "GND_LOG", "GND_BUS"
    v3, v3b, v5, v5b = "3V3_LOG", "3V3_BUS", "5V_USB", "5V_BUS"

    parts: list[Inst] = [
        Inst("tap:USB-C", "J2", "USB-C", "Connector_USB:USB_C_Receptacle_GCT_USB4105-xx-A_16P_TopMnt_Horizontal", {
            "A4": v5, "B4": v5, "A9": v5, "B9": v5,
            "A1": gnd_l, "B1": gnd_l, "A12": gnd_l, "B12": gnd_l,
            "A5": "CC1", "B5": "CC2",
            "A6": "USB_DP_C", "B6": "USB_DP_C", "A7": "USB_DN_C", "B7": "USB_DN_C",
            "SH": gnd_l,
        }, description="Logic power and native USB. Both plug orientations are tied. Shell is logic ground."),
        Inst("tap:R", "R8", "5.1k", "Resistor_SMD:R_0603_1608Metric", {"1": "CC1", "2": gnd_l}),
        Inst("tap:R", "R9", "5.1k", "Resistor_SMD:R_0603_1608Metric", {"1": "CC2", "2": gnd_l}),
        Inst("tap:AP7361", "U6", "AP7361C-33E-13", "Package_TO_SOT_SMD:SOT-223-3_TabPin2", {
            "1": v5, "2": gnd_l, "3": v3,
        }, description="SOT-223 pin 1 IN, pin 2 GND, pin 3 OUT. Tab is pin 2."),
        Inst("tap:C", "C4", "100nF", "Capacitor_SMD:C_0402_1005Metric", {"1": v5, "2": gnd_l}, description="U6 input"),
        Inst("tap:C", "C1", "10uF", "Capacitor_SMD:C_0805_2012Metric", {"1": v3, "2": gnd_l}, description="3V3_LOG bulk"),
        Inst("tap:R", "R10", "10k", "Resistor_SMD:R_0603_1608Metric", {"1": v3, "2": "EN"}),
        Inst("tap:C", "C9", "1uF", "Capacitor_SMD:C_0402_1005Metric", {"1": "EN", "2": gnd_l}),
        Inst("tap:SW", "SW2", "RESET", "Button_Switch_THT:SW_PUSH_6mm", {"1": "EN", "2": gnd_l}),
        Inst("tap:R", "R11", "10k", "Resistor_SMD:R_0603_1608Metric", {"1": v3, "2": "IO0"}),
        Inst("tap:SW", "SW1", "BOOT", "Button_Switch_THT:SW_PUSH_6mm", {"1": "IO0", "2": gnd_l}),
        Inst("tap:R", "R12", "330", "Resistor_SMD:R_0603_1608Metric", {"1": "LED", "2": "IO2"}),
        Inst("tap:D", "D3", "LED", "LED_SMD:LED_0603_1608Metric", {"1": gnd_l, "2": "LED"}, description="Pin 1 is the cathode, on the marked pad. Pin 2 is the anode."),
        Inst("tap:R", "R14", "22", "Resistor_SMD:R_0603_1608Metric", {"1": "USB_DP_C", "2": "USB_DP"}),
        Inst("tap:R", "R15", "22", "Resistor_SMD:R_0603_1608Metric", {"1": "USB_DN_C", "2": "USB_DN"}),
        Inst("tap:R", "R4", "4.7k", "Resistor_SMD:R_0603_1608Metric", {"1": v3, "2": "SDA_LOG"}),
        Inst("tap:R", "R5", "4.7k", "Resistor_SMD:R_0603_1608Metric", {"1": v3, "2": "SCL_LOG"}),
        Inst("tap:TP", "TP1", "TWAI_TX", "TestPoint:TestPoint_Pad_D1.5mm", {"1": "TWAI_TX"}),
        Inst("tap:PWR_FLAG", "#FLG01", "PWR_FLAG", "", {"1": v5}, bom=False, board=False),
        Inst("tap:PWR_FLAG", "#FLG02", "PWR_FLAG", "", {"1": gnd_l}, bom=False, board=False),
        Inst("tap:PWR_FLAG", "#FLG04", "PWR_FLAG", "", {"1": v3}, bom=False, board=False),
        Inst("tap:PWR_FLAG", "#FLG05", "PWR_FLAG", "", {"1": v5b}, bom=False, board=False),
        Inst("tap:PWR_FLAG", "#FLG06", "PWR_FLAG", "", {"1": v3b}, bom=False, board=False),
        Inst("tap:ESP32-S3-WROOM-1", "U1", "ESP32-S3-WROOM-1-N8", "RF_Module:ESP32-S3-WROOM-1", {
            "2": v3, "1": gnd_l, "41": gnd_l, "40": gnd_l,
            "3": "EN", "27": "IO0", "38": "IO2", "4": "CAN_RX", "5": "TWAI_TX",
            "6": "SDA_LOG", "7": "SCL_LOG", "13": "USB_DN", "14": "USB_DP",
        }, description="Module pads follow the Espressif pin table. GPIO5 does not reach the transceiver."),
        Inst("tap:ISO1042", "U2", "ISO1042BDW", "Package_SO:SOIC-16W_7.5x10.3mm_P1.27mm", {
            "1": v3, "2": gnd_l, "8": gnd_l, "3": v3, "5": "CAN_RX",
            "16": v5b, "11": v5b, "9": gnd_b, "10": gnd_b, "15": gnd_b,
            "13": "CANH", "12": "CANL",
            "4": None, "6": None, "7": None, "14": None,
        }, description="TXD pin 3 tied to VCC1. VCC2 pins 11 and 16 are tied. DW-16."),
        Inst("tap:C", "C2", "100nF", "Capacitor_SMD:C_0402_1005Metric", {"1": v3, "2": gnd_l}, description="U2 VCC1"),
        Inst("tap:C", "C3", "100nF", "Capacitor_SMD:C_0402_1005Metric", {"1": v5b, "2": gnd_b}, description="U2 VCC2"),
        Inst("tap:CMC", "L1", "ACT45B-510-2P", "can-modbus-tap:ACT45B-510-2P", {
            "1": "CANH_J", "2": "CANH", "4": "CANL_J", "3": "CANL",
        }, description="Windings are 1-2 and 4-3."),
        Inst("tap:NUP2105", "D1", "NUP2105LT1G", "Package_TO_SOT_SMD:SOT-23", {
            "1": "CANH", "2": "CANL", "3": gnd_b,
        }),
        Inst("tap:JP", "JP1", "TERM", "Connector_PinHeader_2.54mm:PinHeader_1x02_P2.54mm_Vertical", {
            "1": "CANH", "2": "TERM",
        }, description="Leave open. Close only at the physical end of the bus."),
        Inst("tap:R", "R13", "120", "Resistor_SMD:R_0603_1608Metric", {"1": "TERM", "2": "CANL"}, dnp=True,
             description="DNP. In series with JP1."),
        Inst("tap:USB-A", "J1", "USB-A plug", "Connector_USB:USB3_A_Plug_Wuerth_692112030100_Horizontal", {
            "1": "24V", "2": "CANL_J", "3": "CANH_J", "4": gnd_b, "SH": gnd_b,
        }, description="Male plug, not a receptacle. Pin 1 is +24 V sense, pin 2 CANL, pin 3 CANH, pin 4 GND, shell is bus ground."),
        Inst("tap:RFM", "U5", "RFM-0505S", "can-modbus-tap:RECOM_RFM-0505S", {
            "1": gnd_l, "2": v5, "3": gnd_b, "4": v5b,
        }, description="SIP4. Pin 1 -Vin, 2 +Vin, 3 -Vout, 4 +Vout. RECOM rates this module 1 kVDC."),
        Inst("tap:C", "C6", "10uF", "Capacitor_SMD:C_0805_2012Metric", {"1": v5b, "2": gnd_b}),
        Inst("tap:PWR_FLAG", "#FLG03", "PWR_FLAG", "", {"1": gnd_b}, bom=False, board=False),
        Inst("tap:R", "R1", "91.0k", "Resistor_SMD:R_0603_1608Metric", {"1": "24V", "2": "DIV"}),
        Inst("tap:R", "R2", "12.0k", "Resistor_SMD:R_0603_1608Metric", {"1": "DIV", "2": gnd_b}),
        Inst("tap:C", "C8", "100nF", "Capacitor_SMD:C_0402_1005Metric", {"1": "DIV", "2": gnd_b}),
        Inst("tap:R", "R3", "1k", "Resistor_SMD:R_0603_1608Metric", {"1": "DIV", "2": "AIN0"}),
        Inst("tap:D", "D2", "BZT52C3V6", "Diode_SMD:D_SOD-123", {"1": "AIN0", "2": gnd_b}, description="Pin 1 is the cathode, at AIN0. Pin 2 is the anode, at bus ground."),
        Inst("tap:ADS1115", "U4", "ADS1115IDGSR", "Package_SO:MSOP-10_3x3mm_P0.5mm", {
            "1": gnd_b, "3": gnd_b, "4": "AIN0", "5": None, "6": None, "7": None,
            "2": None, "8": v3b, "9": "SDA_BUS", "10": "SCL_BUS",
        }, description="ADDR to bus ground selects I2C 0x48. DGS pin numbers."),
        Inst("tap:ISO1640", "U3", "ISO1640BD", "Package_SO:SOIC-8_3.9x4.9mm_P1.27mm", {
            "1": v3, "2": "SDA_LOG", "3": "SCL_LOG", "4": gnd_l,
            "8": v3b, "7": "SDA_BUS", "6": "SCL_BUS", "5": gnd_b,
        }),
        Inst("tap:R", "R6", "4.7k", "Resistor_SMD:R_0603_1608Metric", {"1": v3b, "2": "SDA_BUS"}),
        Inst("tap:R", "R7", "4.7k", "Resistor_SMD:R_0603_1608Metric", {"1": v3b, "2": "SCL_BUS"}),
        Inst("tap:AP2112", "U7", "AP2112K-3.3", "Package_TO_SOT_SMD:SOT-23-5", {
            "1": v5b, "2": gnd_b, "3": v5b, "4": None, "5": v3b,
        }, description="SOT-23-5 pin 1 VIN, pin 2 GND, pin 3 EN, pin 4 NC, pin 5 VOUT. EN tied to VIN."),
        Inst("tap:C", "C5", "100nF", "Capacitor_SMD:C_0402_1005Metric", {"1": v3b, "2": gnd_b}, description="U7 output"),
        Inst("tap:C", "C7", "10uF", "Capacitor_SMD:C_0805_2012Metric", {"1": v3b, "2": gnd_b}),
    ]

    notes = [
        "Listen-only classic CAN tap. The USB-A plug is the equipment connector and is not USB.",
        "Wires join every pin of a net. GND_LOG and GND_BUS are separate nets and are not connected.",
        "GND_LOG and GND_BUS meet nowhere. Keep an 8 mm empty slot under U2, U3, and U5.",
        "U2 TXD is tied to 3V3_LOG. GPIO5 is TP1 and does not reach the transceiver.",
        "R13 is not populated. JP1 stays open unless this board is the end of the bus.",
        "Meter the equipment port before connecting J1. Pin 1 is the 24 V sense pin in this drawing.",
    ]
    return symbols, parts, notes


# Sheet routing bounds, in 1.27 mm grid units. A1 is 662 by 468.
XMAX = 648
YMAX = 440
POWER_NETS = {"GND_LOG", "GND_BUS", "3V3_LOG", "3V3_BUS", "5V_USB", "5V_BUS"}
Pt = tuple[int, int]
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

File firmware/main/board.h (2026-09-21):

#pragma once

#include "driver/gpio.h"
#include "driver/i2c.h"

/* TWAI TX is a test point only. The transceiver TXD pin is tied to 3V3
 * on the board, so this GPIO cannot drive the bus even if firmware tries. */
#define TAP_TWAI_TX GPIO_NUM_5
#define TAP_TWAI_RX GPIO_NUM_4

#define TAP_I2C_SDA GPIO_NUM_6
#define TAP_I2C_SCL GPIO_NUM_7
#define TAP_I2C_PORT I2C_NUM_0
#define TAP_ADS_ADDR 0x48

#define TAP_LED GPIO_NUM_2

#define TAP_REC_SIZE 32
#define TAP_REC_MAGIC 0xC0FFEE42u

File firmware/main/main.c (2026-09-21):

#include <ctype.h>
#include <stdio.h>
#include <string.h>

#include "bus_sense.h"
#include "can_sniff.h"
#include "capture_log.h"
#include "esp_event.h"
#include "esp_log.h"
#include "esp_mac.h"
#include "esp_netif.h"
#include "esp_wifi.h"
#include "freertos/FreeRTOS.h"
#include "freertos/event_groups.h"
#include "freertos/queue.h"
#include "nvs_flash.h"
#include "sdkconfig.h"
#include "uploader.h"

static const char *TAG = "tap";
static EventGroupHandle_t s_wifi;

static void wifi_handler(void *arg, esp_event_base_t base, int32_t id, void *data) {
    (void)arg;
    if (base == WIFI_EVENT && id == WIFI_EVENT_STA_START) {
        esp_wifi_connect();
    } else if (base == WIFI_EVENT && id == WIFI_EVENT_STA_DISCONNECTED) {
        xEventGroupClearBits(s_wifi, TAP_WIFI_CONNECTED_BIT);
        ESP_LOGW(TAG, "wifi disconnected, retrying");
        esp_wifi_connect();
    } else if (base == IP_EVENT && id == IP_EVENT_STA_GOT_IP) {
        ip_event_got_ip_t *event = (ip_event_got_ip_t *)data;
        ESP_LOGI(TAG, "wifi ip " IPSTR, IP2STR(&event->ip_info.ip));
        xEventGroupSetBits(s_wifi, TAP_WIFI_CONNECTED_BIT);
    }
}

static void make_device_id(char *dst, size_t n) {
    size_t j = 0;
    dst[0] = 0;
    for (size_t i = 0; CONFIG_TAP_DEVICE_ID[i] != 0 && j + 1 < n; i++) {
        unsigned char c = (unsigned char)CONFIG_TAP_DEVICE_ID[i];
        if (isalnum(c) || c == '-' || c == '_') {
            dst[j++] = (char)c;
            dst[j] = 0;
        }
    }
    if (dst[0] != 0) {
        return;
    }
    uint8_t mac[6];
    esp_read_mac(mac, ESP_MAC_WIFI_STA);
    snprintf(dst, n, "%02x%02x%02x%02x%02x%02x", mac[0], mac[1], mac[2], mac[3], mac[4], mac[5]);
}

static void wifi_start(void) {
    s_wifi = xEventGroupCreate();
    ESP_ERROR_CHECK(esp_netif_init());
    ESP_ERROR_CHECK(esp_event_loop_create_default());
    esp_netif_create_default_wifi_sta();
    wifi_init_config_t cfg = WIFI_INIT_CONFIG_DEFAULT();
    ESP_ERROR_CHECK(esp_wifi_init(&cfg));
    ESP_ERROR_CHECK(esp_event_handler_register(WIFI_EVENT, ESP_EVENT_ANY_ID, wifi_handler, NULL));
    ESP_ERROR_CHECK(esp_event_handler_register(IP_EVENT, IP_EVENT_STA_GOT_IP, wifi_handler, NULL));

    wifi_config_t wifi = {0};
    strncpy((char *)wifi.sta.ssid, CONFIG_TAP_WIFI_SSID, sizeof wifi.sta.ssid - 1);
    strncpy((char *)wifi.sta.password, CONFIG_TAP_WIFI_PASSWORD, sizeof wifi.sta.password - 1);
    wifi.sta.threshold.authmode = CONFIG_TAP_WIFI_PASSWORD[0] == 0 ? WIFI_AUTH_OPEN : WIFI_AUTH_WPA2_PSK;
    ESP_ERROR_CHECK(esp_wifi_set_mode(WIFI_MODE_STA));
    ESP_ERROR_CHECK(esp_wifi_set_config(WIFI_IF_STA, &wifi));
    ESP_ERROR_CHECK(esp_wifi_start());
}

void app_main(void) {
    esp_err_t err = nvs_flash_init();
    if (err == ESP_ERR_NVS_NO_FREE_PAGES || err == ESP_ERR_NVS_NEW_VERSION_FOUND) {
        ESP_ERROR_CHECK(nvs_flash_erase());
        err = nvs_flash_init();
    }
    ESP_ERROR_CHECK(err);
    ESP_ERROR_CHECK(capture_log_init());
    if (bus_sense_init() != ESP_OK) {
        ESP_LOGW(TAG, "24 V sense unavailable; CAN capture still runs");
    }

    char device_id[32];
    make_device_id(device_id, sizeof device_id);
    ESP_LOGI(TAG, "device %s", device_id);

    if (CONFIG_TAP_WIFI_SSID[0] == 0) {
        s_wifi = xEventGroupCreate();
        ESP_LOGW(TAG, "Wi-Fi SSID is empty; recording to flash only");
    } else {
        wifi_start();
    }

    QueueHandle_t frames = xQueueCreate(128, sizeof(cap_frame_t));
    uploader_start(frames, s_wifi, device_id);
    can_sniff_start(frames);
}

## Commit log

2026-09-21 Add a listen-only ESP32 CAN tap and MODBUS collector.
    Record classic CAN frames from a 24 V USB-A accessory port and pair MODBUS payloads without letting the probe drive the bus.
    [bom.csv, partitions.csv]
2026-09-22 Add the routed KiCad board for the listen-only CAN tap.
    The schematic and two-layer layout keep the logic and bus grounds apart, with the isolation slot and the parts a fab quote needs.
    [bom.csv, can-modbus-tap.kicad_pcb, can-modbus-tap.kicad_sch]
2026-09-22 Shrink the routed CAN tap board to 90 by 66 mm.
    [can-modbus-tap.kicad_pcb]
2026-09-22 Add the Reliable Reefs mark to the front silkscreen.
    [can-modbus-tap.kicad_pcb]
2026-10-08 add gerbers
    [can-modbus-tap-B_Cu.gbl, can-modbus-tap-B_Mask.gbs, can-modbus-tap-B_Paste.gbp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]
